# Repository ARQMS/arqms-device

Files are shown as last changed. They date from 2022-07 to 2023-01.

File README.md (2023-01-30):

View this project on [CADLAB.io](https://cadlab.io/project/26464). 

# Humi Device
The humi device is a portable air qualitity measure device which is connected to a MQTT Broker. This enables
a flexible way the measure the air qualitity without any cable management. The device is powered by a 2000mAh battery
and can be recharged with any 5V USB-C charger.<br />
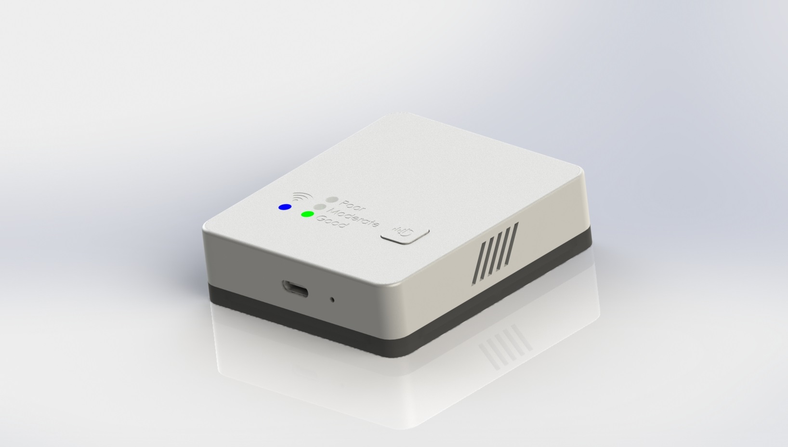
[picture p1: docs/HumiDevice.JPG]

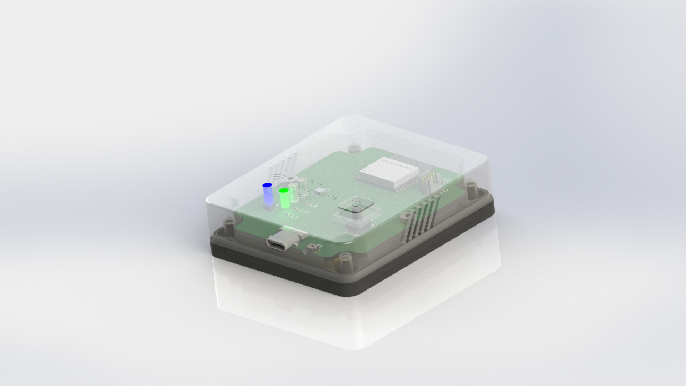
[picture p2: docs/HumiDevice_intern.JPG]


# Contribute
The project is documented in Github Wiki Page

## IDE and SDK
The ESP32-C3 is used as main CPU and WLAN module. Ensure you have installed the ESP-IDF Framework on your 
development machine according to [docs](https://docs.espressif.com/projects/esp-idf/en/latest/esp32c3/get-started/index.html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) or quick install instruction from [YoutTube](https://www.youtube.com/watch?v=byVPAfodTyY)

As standard IDE Visual Studio Code is used, open the `firmware` Folder.

# Knowing Issues
**Rev0** fixed in Rev1
- [x] PCB - Label "2000mAh @ 3.7V" is mirrored pn PCB back side
- [x] PCB - CN1 Label is mirrored on PCB back side
- [x] PCB - Wrong Buck Converter Footprint
- [x] BOM - Wrong Supplier Part Number for B5. Should be SSAL220100
- [x] Case - Bottom case has infinity small border for screw holder

**Rev1**
- [ ] PCB - USB Port is too small after JLCPCB fabrication
- [ ] PCB - If HW Switch is soldered, ESP does not start anymore. Workaround remove R23
- [ ] PCB - Green LED is very bright, increase resistor
- [ ] PCB - Wrong Q1 footprint

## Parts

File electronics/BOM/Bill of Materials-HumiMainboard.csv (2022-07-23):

Quantity | Designator | Description | Case/Package | Supplier 1 | JLCPCB | Manufacturer 1 | Manufacturer Part Number 1 | Name
1 | L1 | 2.2uH ±10% 2.45A 60mO SMD,3.0x3.0x1.5mm Power Inductors RoHS |  | Mouser | C43389 | TDK | VLS3015CX-2R2M-1 | SWPA3015S2R2MT
1 | D2 | SEMTECH - SRV05-4.TCT - ESD Protection Device, TVS, 17.5 V, SOT-23, 6 Pins, 5 V, 300 W | SOT-23 | Mouser | C13612 | Semtech | SRV05-4.TCT | SRV05-4.TCT
3 | SB1, SB2, SB3 | CHIP RESISTOR - SURFACE MOUNT 0OHMS ±1% 1/4W 0603 ROHS | 0603 |  |  |  |  | Solderbridge
1 | U4 | 2.5MHz 1.0A Synchronous Step Down Regulator in SOT23-5 | SOT-23-5 |  |  | Semtech | SC4626ZSKTRT | SC4626ZSKTRT
2 | R25, R26 | Chip Resistor, 100 KOhm, +/- 1%, 0.125 W, -55 to 155 degC, 0805 (2012 Metric), RoHS, Tape and Reel | 0805 | Digi-Key |  | Yageo | RC0805FR-07100KL | RC0805FR-07100KL
1 | Q1 | NST847BDP6T5G Series 45 V 100 mA Dual NPN General Purpose Transistor - SOT-963 |  | LCSC |  | ON Semiconductor | NST847BDP6T5G | NST847BDP6T5G
1 | LD3 | NeoPixel Addressable 1515 LEDs (1.5mm x 1.5mm) - 10 pack |  | Mouser |  | Adafruit Industries | 4492 | NeoPixel 1515
1 | T1 | P-Channel Enhancement Mode Field Effect Transistor 60V 0.12A 10Ohm 3-Pin SOT-23 Surface Mount T/R | SOT-23-3 |  |  | ON Semiconductor | NDS0610-G | NDS0610-G
1 | U3 | USB/AC Battery Charger with Power Path Management 20 QFN 4x4x0.9mm TUBE RoHS Compliant: Yes | QFN | Mouser |  | Microchip | MCP73871-1CCI/ML | MCP73871-1CCI/ML
2 | M1, M2 | M3 Mountinghole |  |  |  |  |  | M3 Mountinghole
1 | BAT1 | 3.7VWire Lead Term Rechargeable Lithium Battery Pack For Power Supply, 2000mAh |  | Eckstein |  | MIKROE | MIKROE-1120 | LiPo Akku
1 | D1 | 5V 5.6V Bidirectional 18.6V 9.4A (8/20us) SOD-523 ESD Protection Devices ROHS | SOD-523 | Mouser | C383211 | MCC | ESD5V0D5B-TP | LESD5D5.0CT1G
1 | LD4 | LED Uni-Color Red 630nm 2-Pin Chip LED T/R | 0603 | Digi-Key | C2286 | Wurth Electronics | 150060RS55040 | KT-0603R
1 | B2 | Switch Tactile N.O. SPST Button Gull Wing 0.05A 32VDC 1VA 200000Cycles 2N SMD Automotive T/R |  | Mouser | C221747 | ITT C&K | KMR221NGLFS | KMR221NGLFS
1 | CN1 | CML 1769 LMP T-1 3/4 INC Midget Screw .2A 2.5V Part of the VCC Family of Products |  | Mouser |  | Adafruit Industries | 1769 | JST-PH-2
2 | B1, B4 | SWITCH TACTILE SPST-NO 0.05A 12V |  | Mouser | C388883 | Panasonic | EVQP7C01P | EVQP7C01P
1 | U1 | 2.4 GHz WiFi, (802.11 b/g/n) and Bluetooth 5 module, Built around ESP32-C3, RISCV, singlecore, 4 MB flash, 15 GPIOs, Onboard |  | Digi-Key |  | Espressif Systems | ESP32-C3-WROOM-02-N4 | ESP32-C3-WROOM-02
1 | R9 |  |  | Mouser |  | Panasonic | ERJ3EKF1001V | ERJ-3EKF1001V
1 | R6 | 665kO ±1% 0.0625W ±100ppm/? 0402 Chip Resistor - Surface Mount RoHS | 0402 | Digi-Key |  | Vishay | CRCW0402665KFKED | CRCW0402665KFKED
2 | R10, R11 | Chip Resistor, 10 KOhm, +/- 1%, 100 mW, -55 to 155 degC, 0603 (1608 Metric), RoHS, Tape and Reel |  |  |  | Vishay | CRCW060310K0FKEA | CRCW060310K0FKEA
3 | C2, C8, C9 | SAMSUNG ELECTRO-MECHANICS - CL31A106KBHNNNE - SMD Multilayer Ceramic Capacitor, 10 µF, 50 V, 1206 [3216 Metric], ± 10%, X5R, CL Series | 1206 | Mouser | C13585 | Samsung | CL31A106KACLNNC | CL31A106KBHNNNE
2 | C4, C5 | Ceramic capacitor SMD-0603 22pF /50V NP0# J +-5%, Samsung, RoHS | 0603 | Mouser | C1653 | Samsung | CL10C220JB8NNNC | CL10C220JB8NNNC
3 | C10, C11, C12 | Ceramic capacitor SMD 0603 4.7 µF 16 V 10 % | 0603 | Mouser | C19666 | Samsung | CL10A475KO8NNNC | CL10A475KO8NNNC
1 | C13 | Ceramic capacitor SMD-0603 22uF /50V NP0# J +-5%, Samsung, RoHS | 0603 | Digi-Key | C1653 | Samsung | CL10A226KQ8NRNE | CL10A226KQ8NRNE
2 | C3, C14 | Cap Ceramic 1uF 50V X5R 10% SMD 0603 85C Cardboard T/R | 0603 | Mouser | C15849 | Samsung | CL10A105KB8NNNC | CL10A105KB8NNNC
6 | C1, C6, C7, C15, C16, C17 | Cap Ceramic 0.1uF 50V X7R 10% SMD 0603 125C Paper T/R | 0603 | Digi-Key | C14663 | Samsung | CL10B104KB8NNWC | CC0603KRX7R9BB104
1 | Q2 | 55V, Dual N-Ch, 35 m? max, Automotive MOSFET, SO8, OptiMOS™, PG-DSO-8-7, RoHS | SOIC | Mouser |  | Infineon | BSO604NS2XUMA1 | BSO604NS2XUMA1
1 | U2 | Pressure, Temperature and Humidity Sensor Digital Output 1.8V 8-Pin LGA | LGA | Digi-Key |  | Bosch Tools | BME680 | BME680
1 | B3 | Switch Tactile N.O. SPST Square Button Gull Wing 0.05A 12VDC 0.98N SMD Bulk | SMD/SMT | Mouser |  | APEM | ADTSM644KV | ADTSM644KV
1 | CN2 | USB Type - Connector, Mid-mount, SMT, CH-0.52, 16pos |  | Mouser |  | Molex | 216990-0001 | 216990-0001
1 | R13 | 5.6kO ±1% 0.1W ±100ppm/? 0603 Chip Resistor - Surface Mount RoHS | 0603 | LCSC | C23189 | Panasonic | ERJU03F5601V | 0603WAF5601T5E
2 | R17, R18 | 5.1kO ±1% 0.1W ±100ppm/? 0603 Chip Resistor - Surface Mount RoHS | 0603 | Mouser | C23186 | Panasonic | ERJU03F5101V | 0603WAF5101T5E
4 | R15, R19, R20, R21 | 470O ±1% 0.1W ±100ppm/? 0603 Chip Resistor - Surface Mount RoHS | 0603 | Mouser | C23179 | Panasonic | ERJU03F4700V | 0603WAF4700T5E
1 | R8 | 330kO ±1% 0.1W ±100ppm/? 0603 Chip Resistor - Surface Mount RoHS | 0603 | LCSC |  | Uniroyal | 0603WAF3303T5E | 0603WAF3303T5E
1 | R14 | 22kO ±1% 0.1W ±200ppm/? 0603 Chip Resistor - Surface Mount RoHS | 0603 | Mouser | C31850 | Panasonic | ERJU03F2202V | 0603WAF2202T5E
1 | R12 | 110kO ±1% 0.1W ±100ppm/? 0603 Chip Resistor - Surface Mount RoHS | 0603 | LCSC |  | Uniroyal | 0603WAF1103T5E | 0603WAF1103T5E
1 | R1 | 10kO ±1% 0.1W ±100ppm/? 0603 Chip Resistor - Surface Mount RoHS | 0603 | Mouser | C25804 | Panasonic | ERJU03F1002V | 0603WAF1002T5E
2 | R7, R16 | 1kO ±1% 0.1W ±100ppm/? 0603 Chip Resistor - Surface Mount RoHS | 0603 | LCSC | C21190 | Uniroyal | 0603WAF1001T5E | 0603WAF1001T5E
5 | R2, R3, R22, R23, R24 | 0O ±1% 0.1W ±200ppm/? 0603 Chip Resistor - Surface Mount RoHS | 0603 |  | C21189 | Royal Electronic Factory | 0603WAF0000T5E | 0603WAF0000T5E
2 | R4, R5 | 100kO ±1% 0.0625W ±100ppm/? 0402 Chip Resistor - Surface Mount RoHS | 0402 | Mouser | C25741 | Panasonic | ERJ-2RKF1003X | 0402WGF1003TCE
3 | LD1, LD2, LD6 | LED Uni-Color Green 518nm 2-Pin Chip LED T/R | 0603 | Farnell | C72043 | Wurth Electronics | 150060GS84000 | 19-217/GHC-YR1S2/3T
1 | LD5 | SMD LED yellow 1.7. . .2.3 V 0603, 19-213/Y2C-CQ2R2L/3T, Everlight Electronics | 0603 | Digi-Key | C72038 | Wurth Electronics | 150060YS55040 | 19-213/Y2C-CQ2R2L/3T

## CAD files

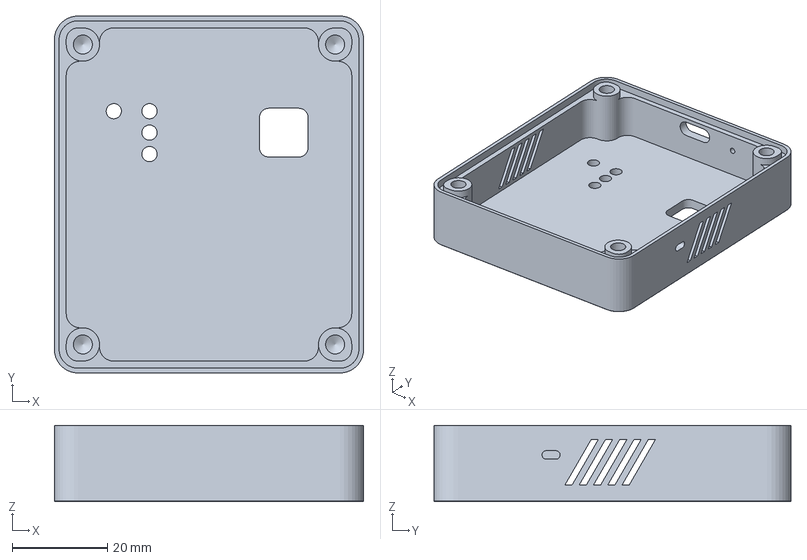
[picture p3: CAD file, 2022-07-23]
housing/CaseTop.3MF
65.0 x 75.0 x 16.0 mm

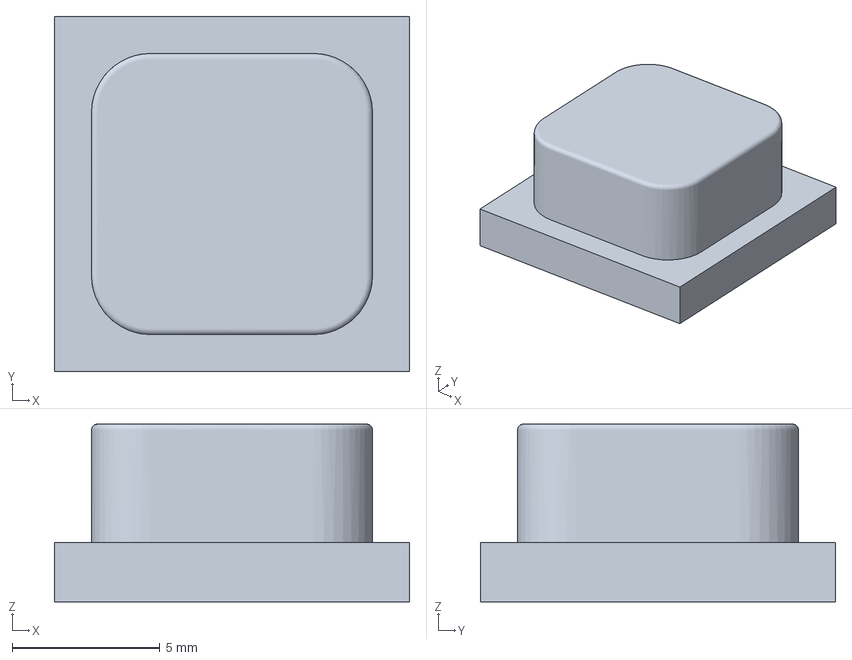
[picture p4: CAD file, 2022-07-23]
housing/Button.3MF
12.0 x 12.0 x 6.01 mm

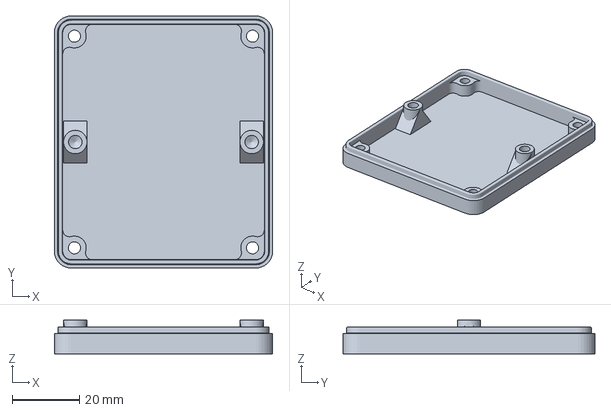
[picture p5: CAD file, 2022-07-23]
housing/CaseBottoml.3MF
65.0 x 75.0 x 10.0 mm

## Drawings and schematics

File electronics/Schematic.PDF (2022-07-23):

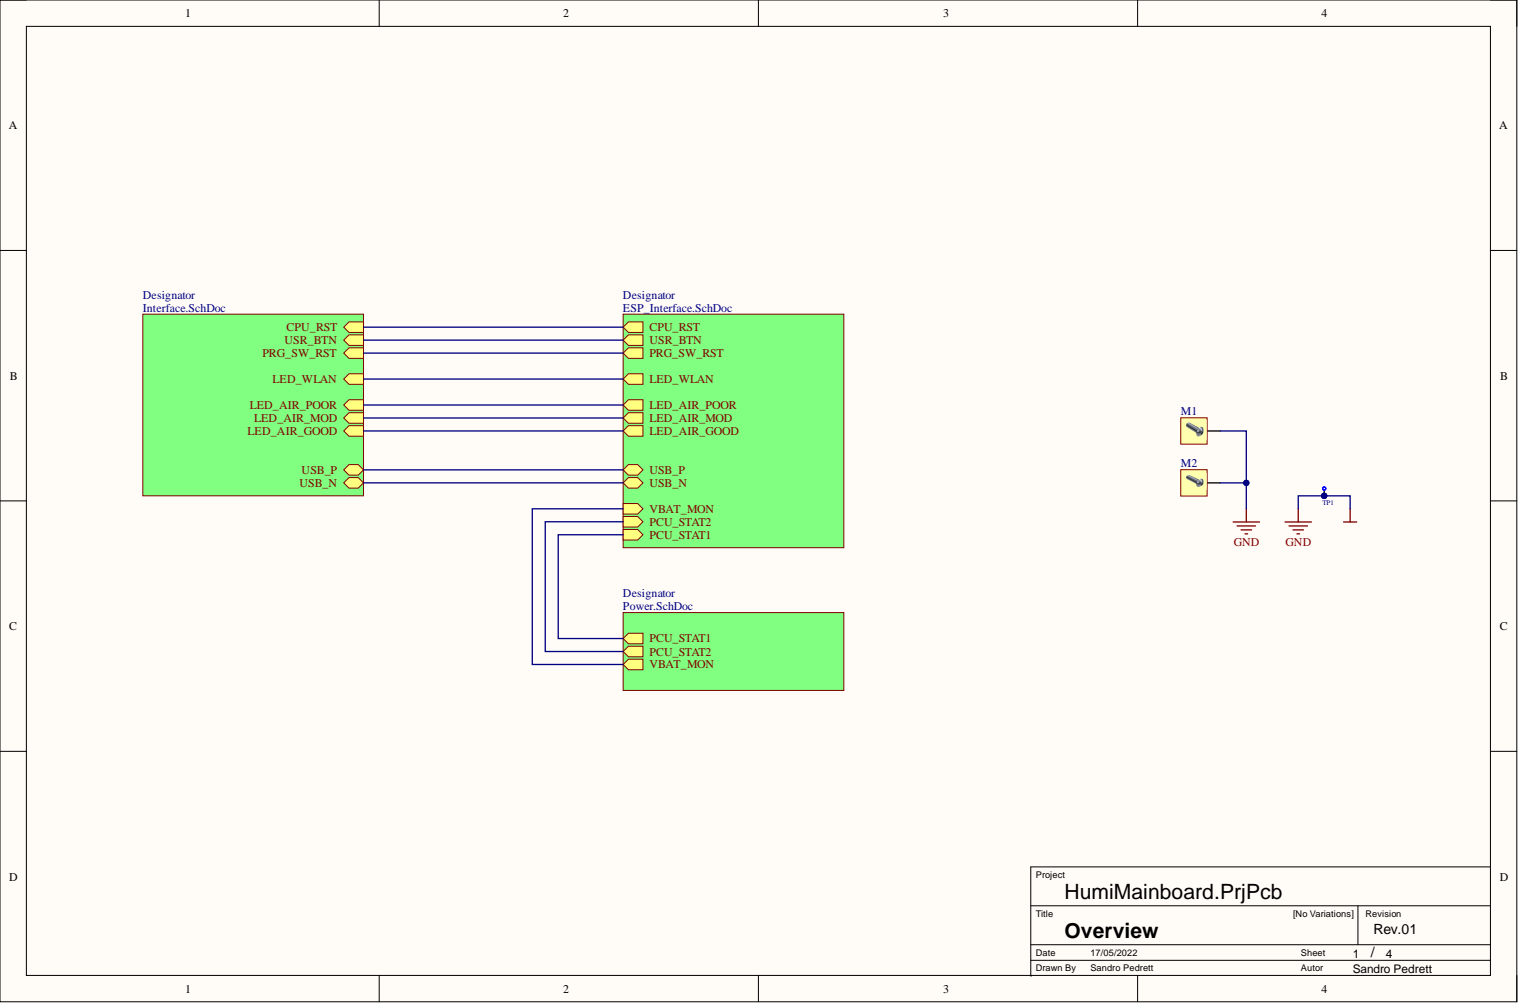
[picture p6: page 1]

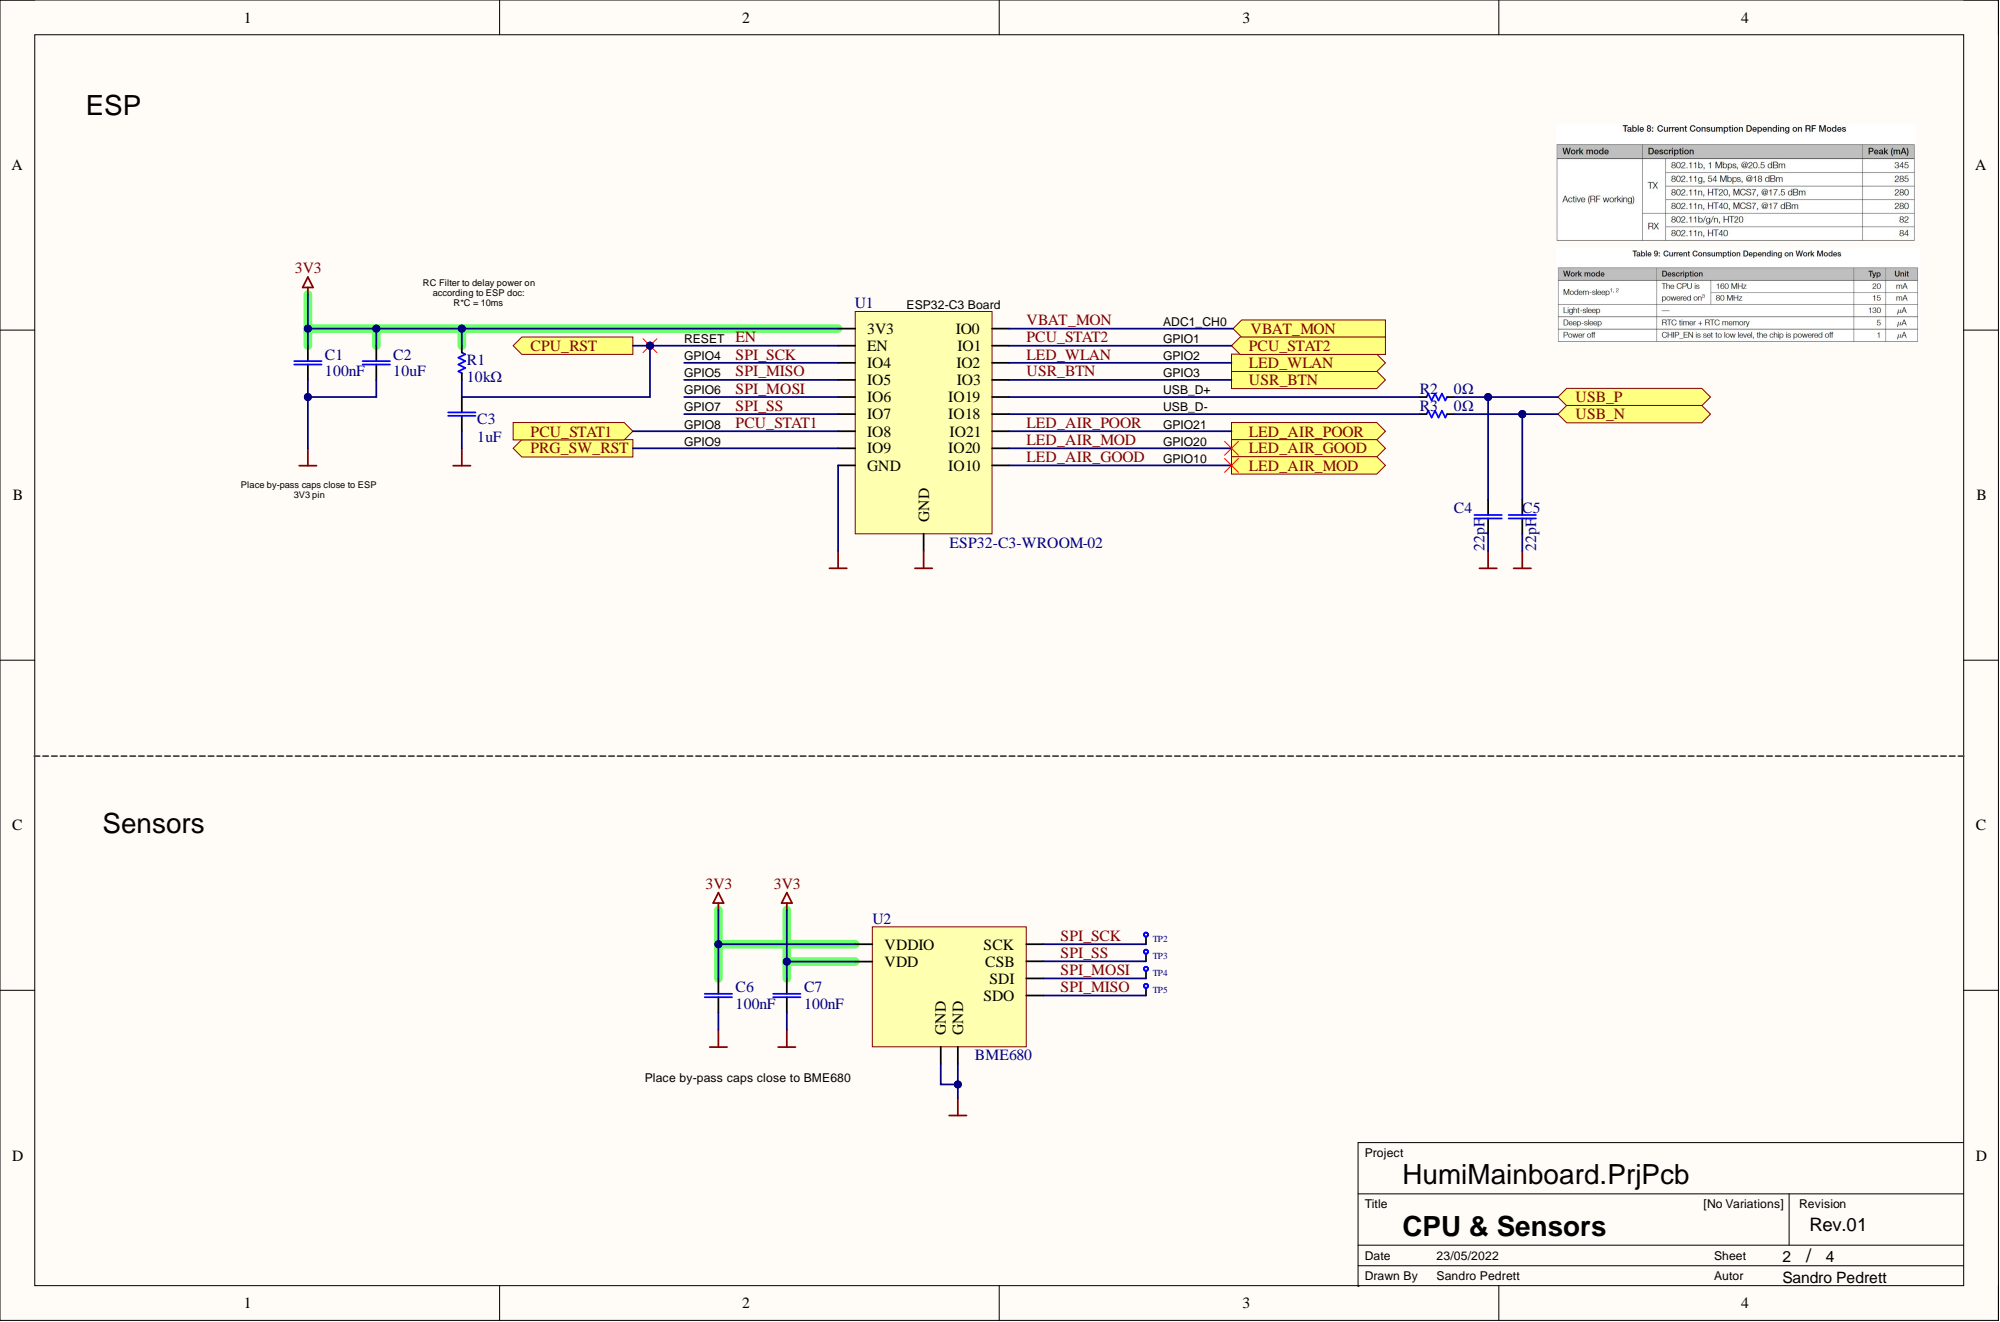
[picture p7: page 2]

RC Filter to delay power on
according to ESP doc:

GPIO4 SPI_SCK R1 SPI_MISO 10kΩ GPIO5 GPIO6 SPI_MOSI

Place by-pass caps close to ESP

Place by-pass caps close to BME680

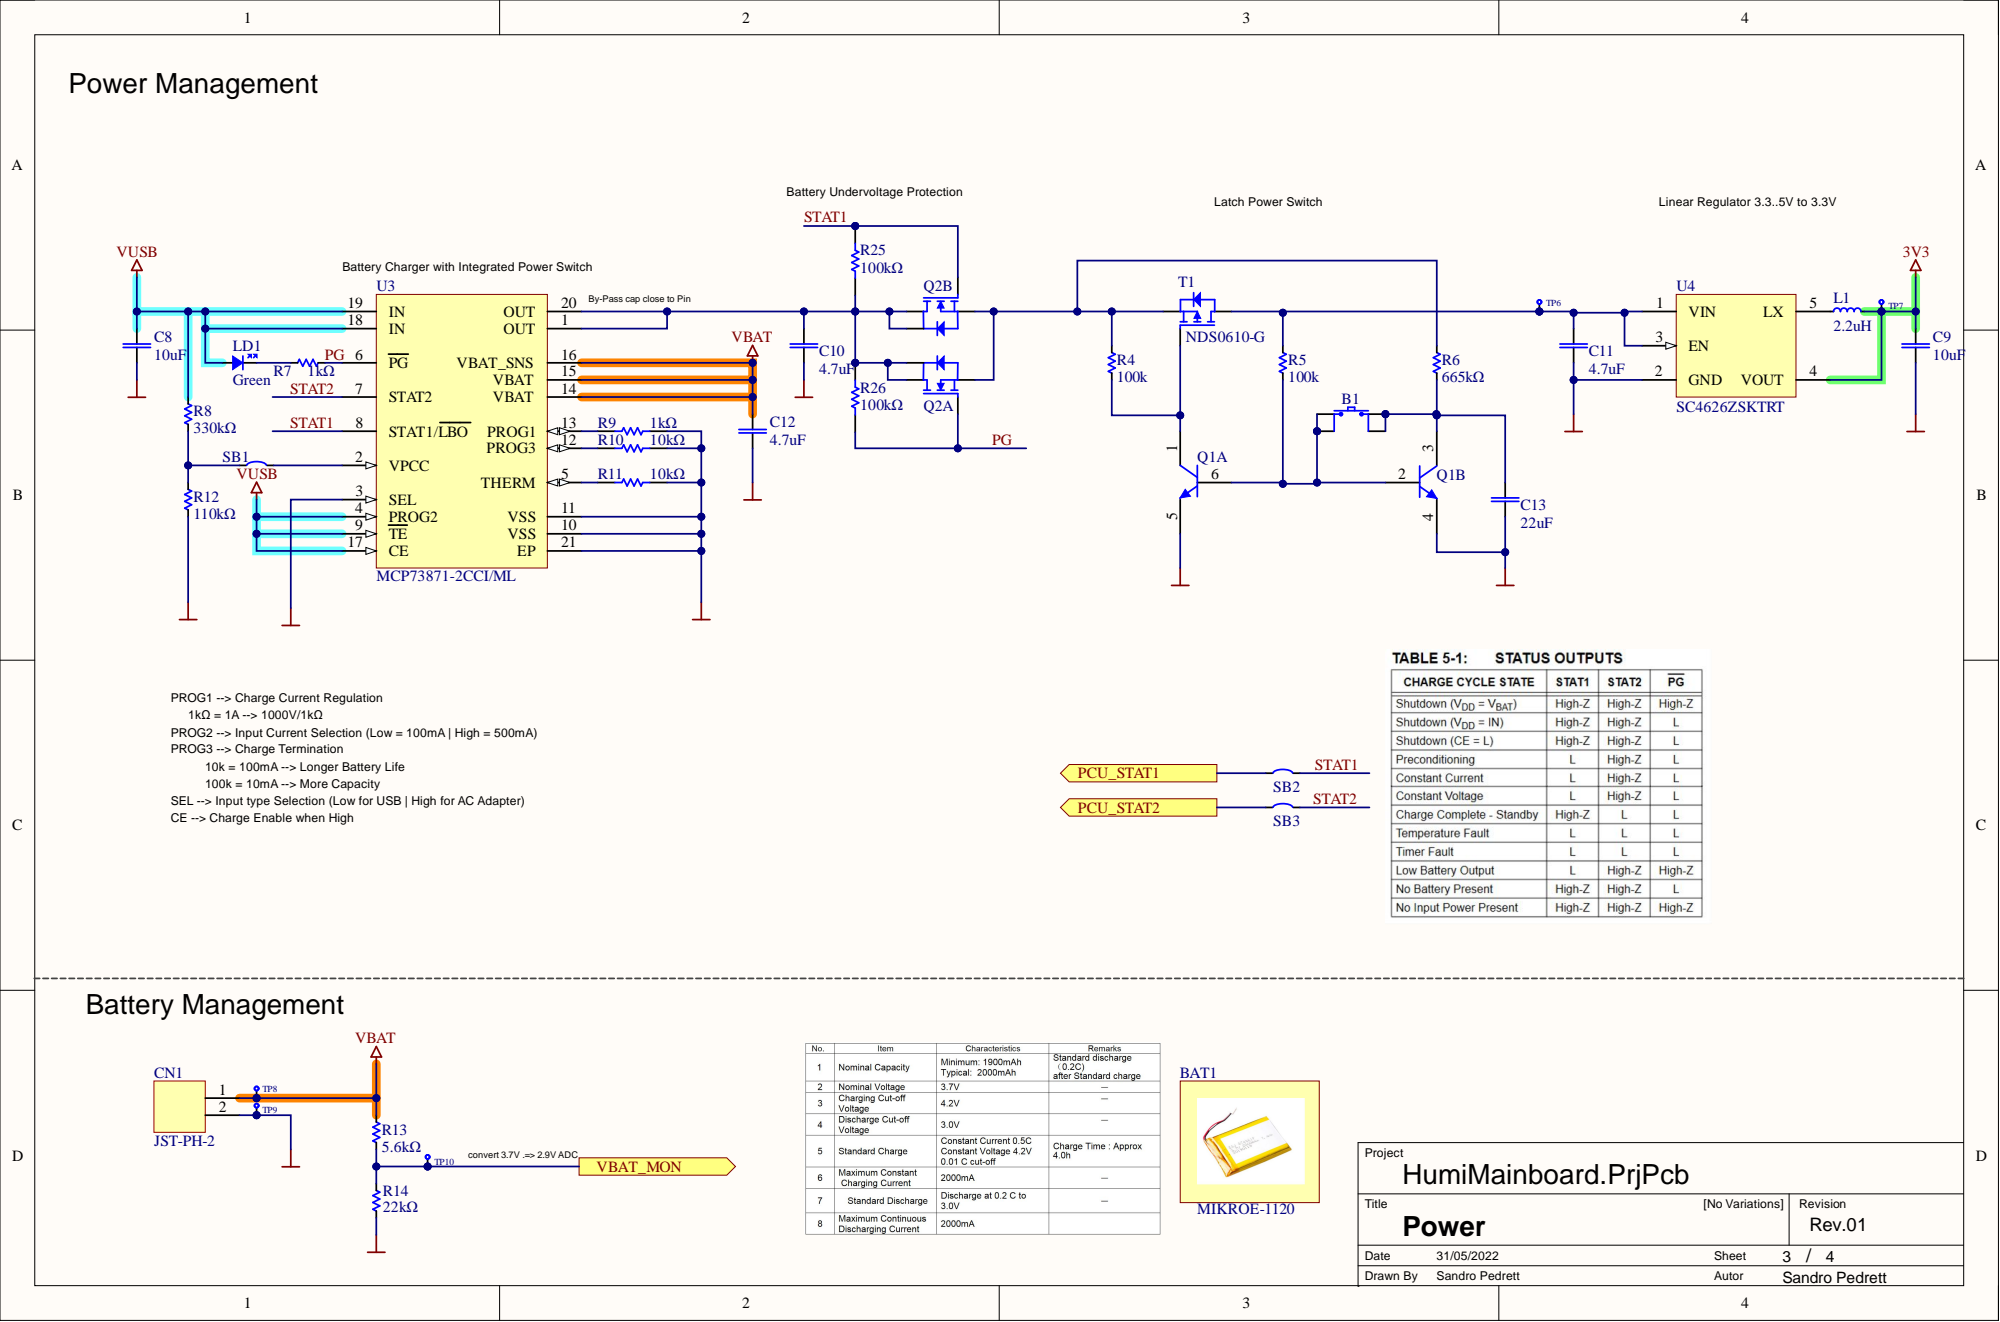
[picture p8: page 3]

Battery Charger with Integrated Power Switch

By-Pass cap close to Pin

PROG1 --> Charge Current Regulation
PROG2 --> Input Current Selection (Low = 100mA | High = 500mA)
PROG3 --> Charge Termination

SEL --> Input type Selection (Low for USB | High for AC Adapter)
CE --> Charge Enable when High

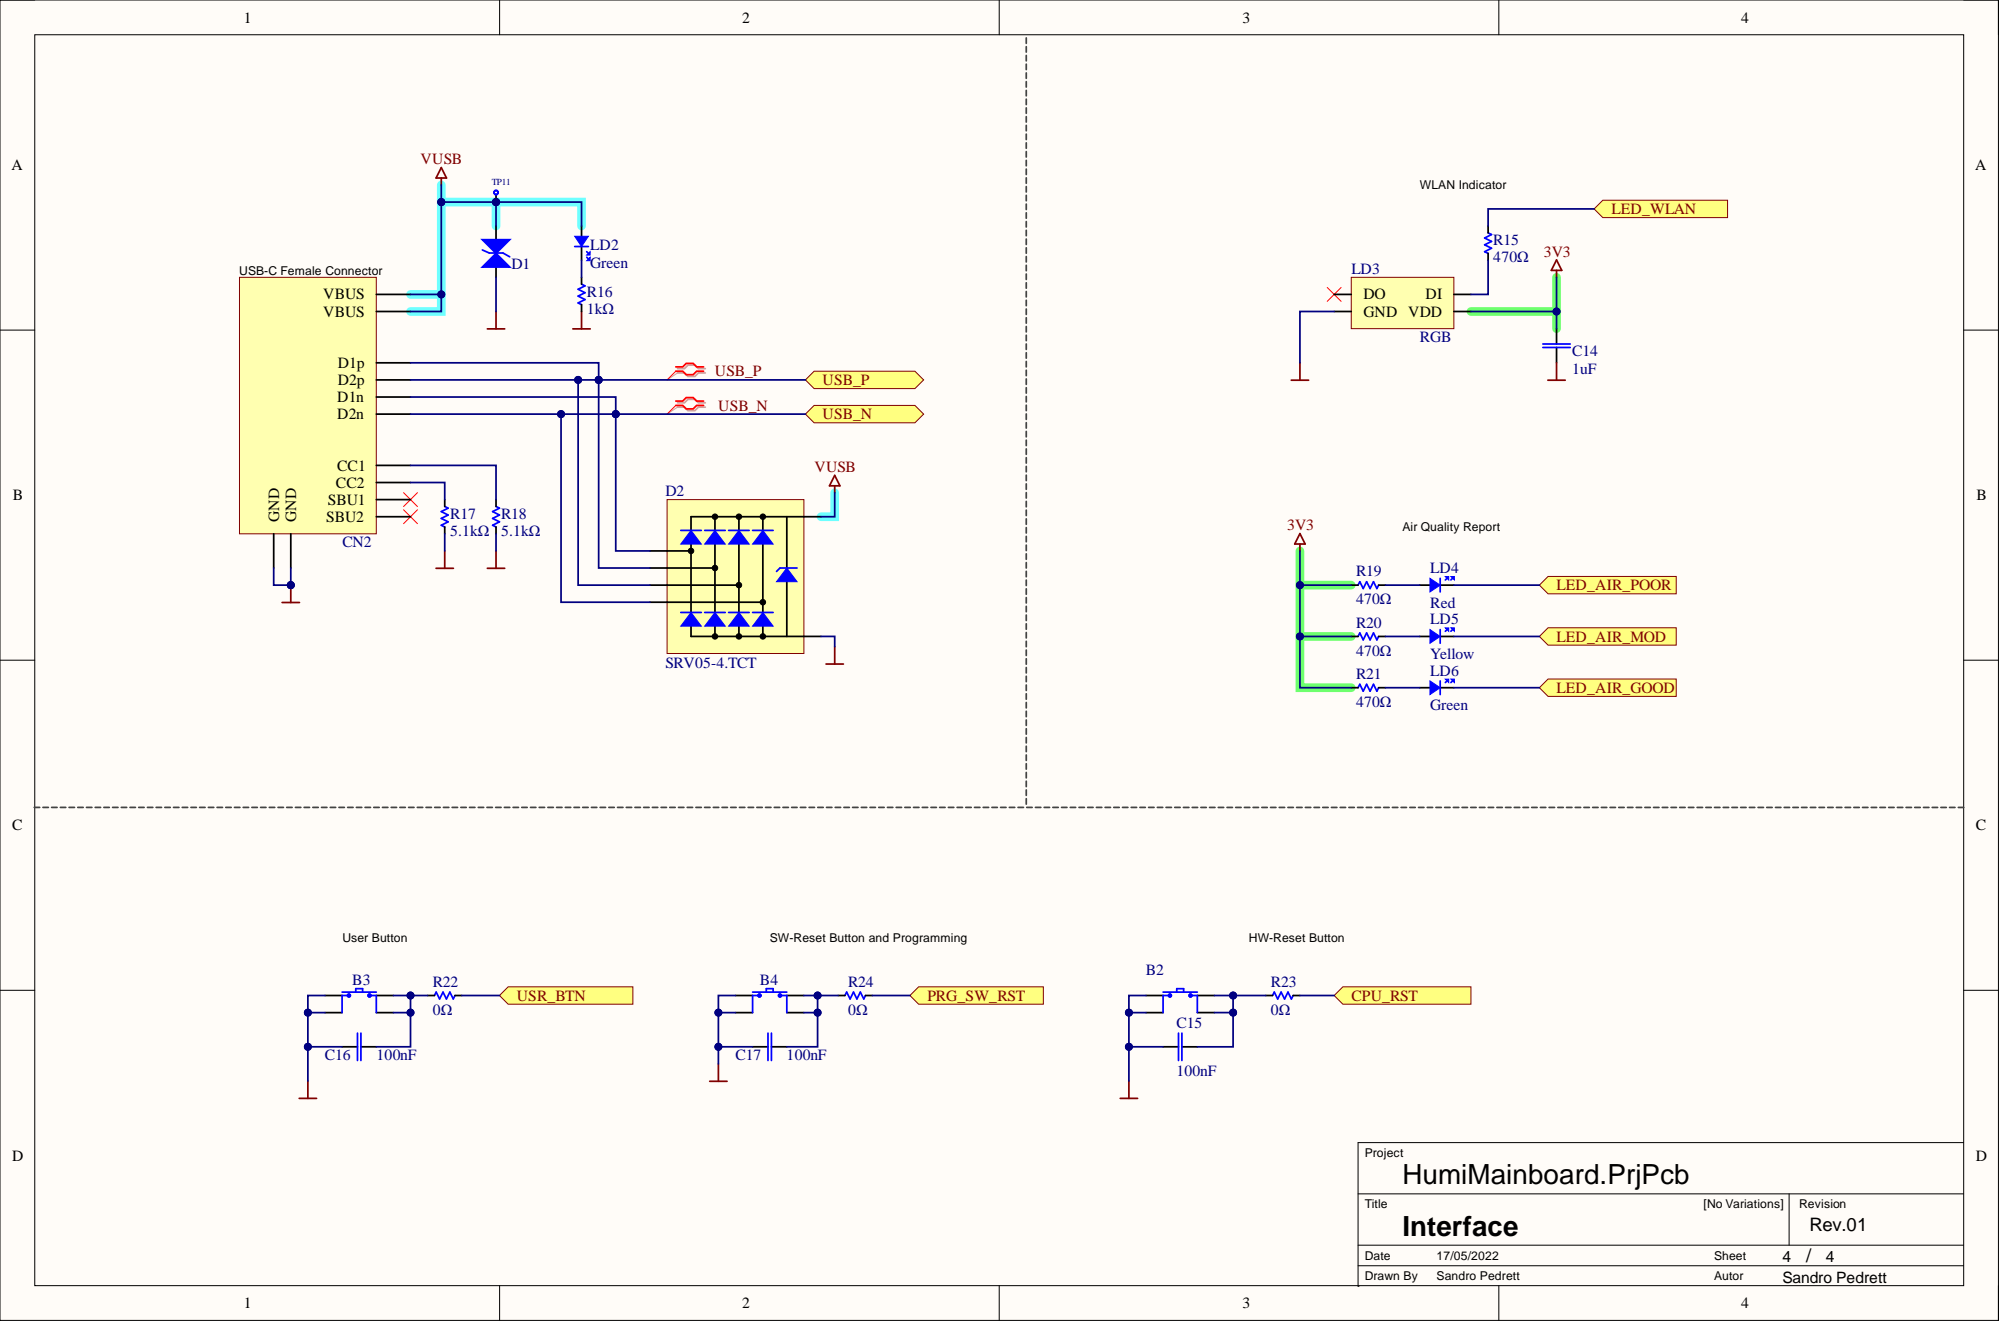
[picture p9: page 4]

USB_N

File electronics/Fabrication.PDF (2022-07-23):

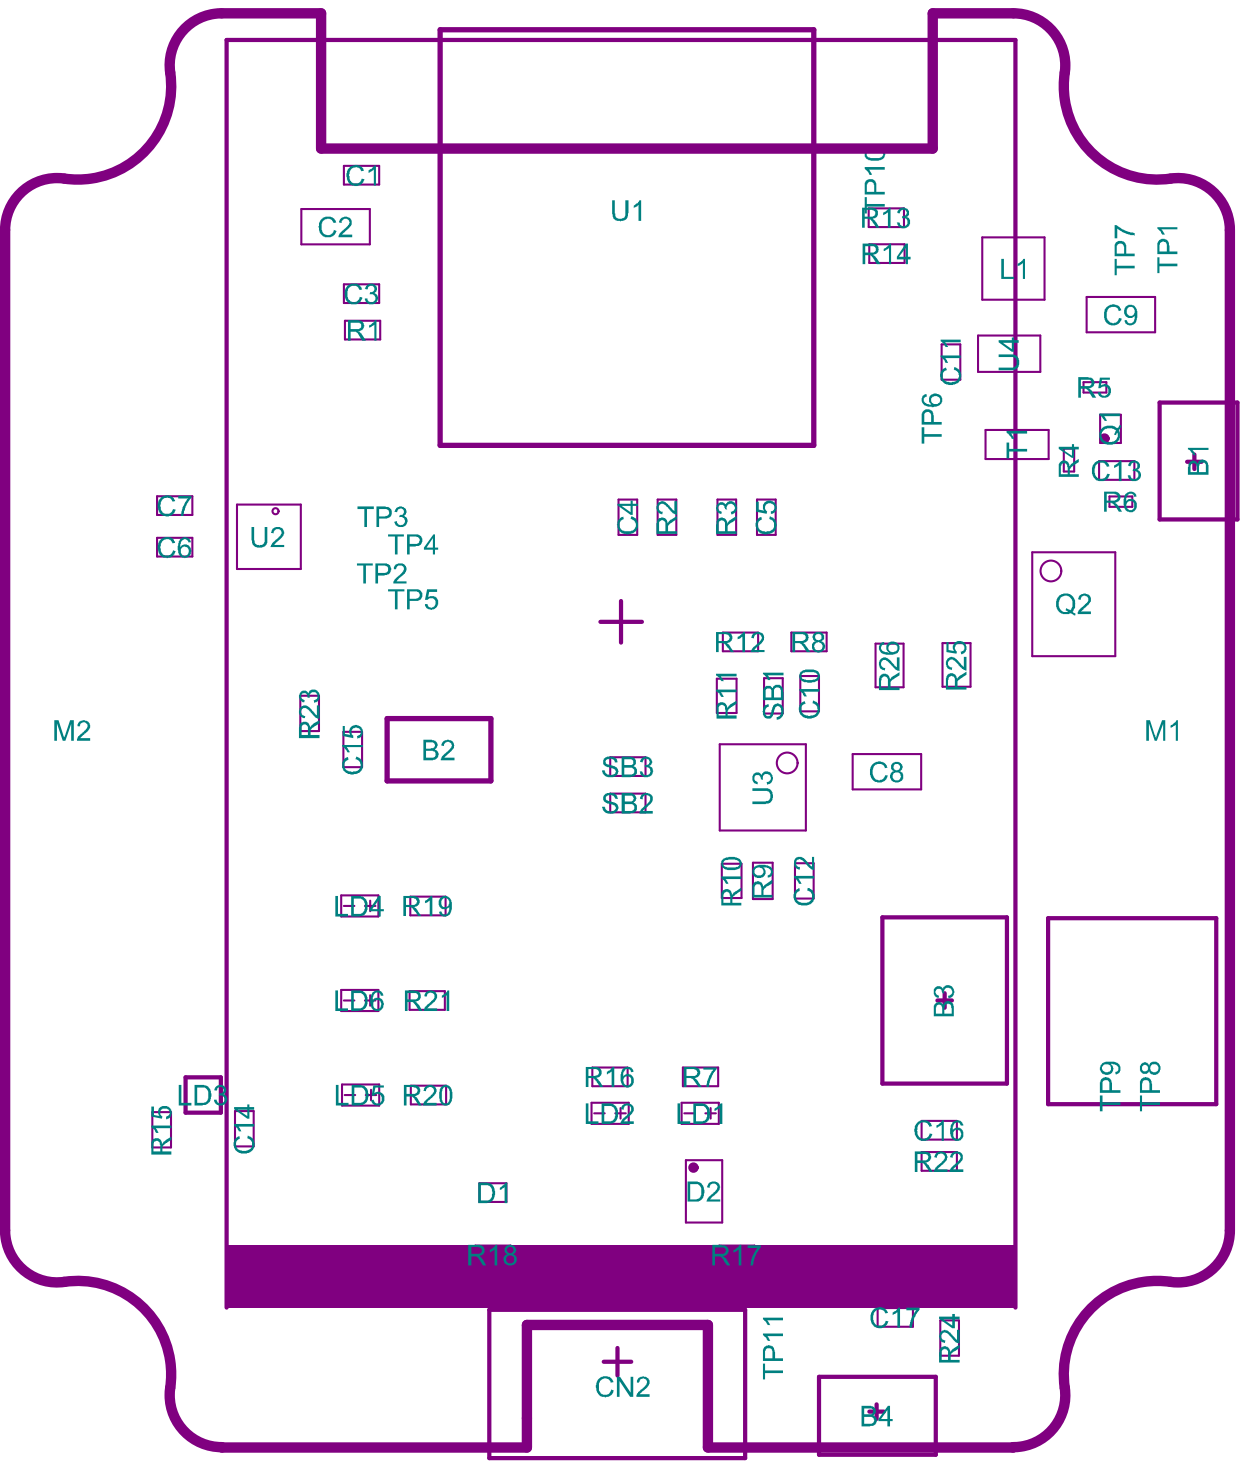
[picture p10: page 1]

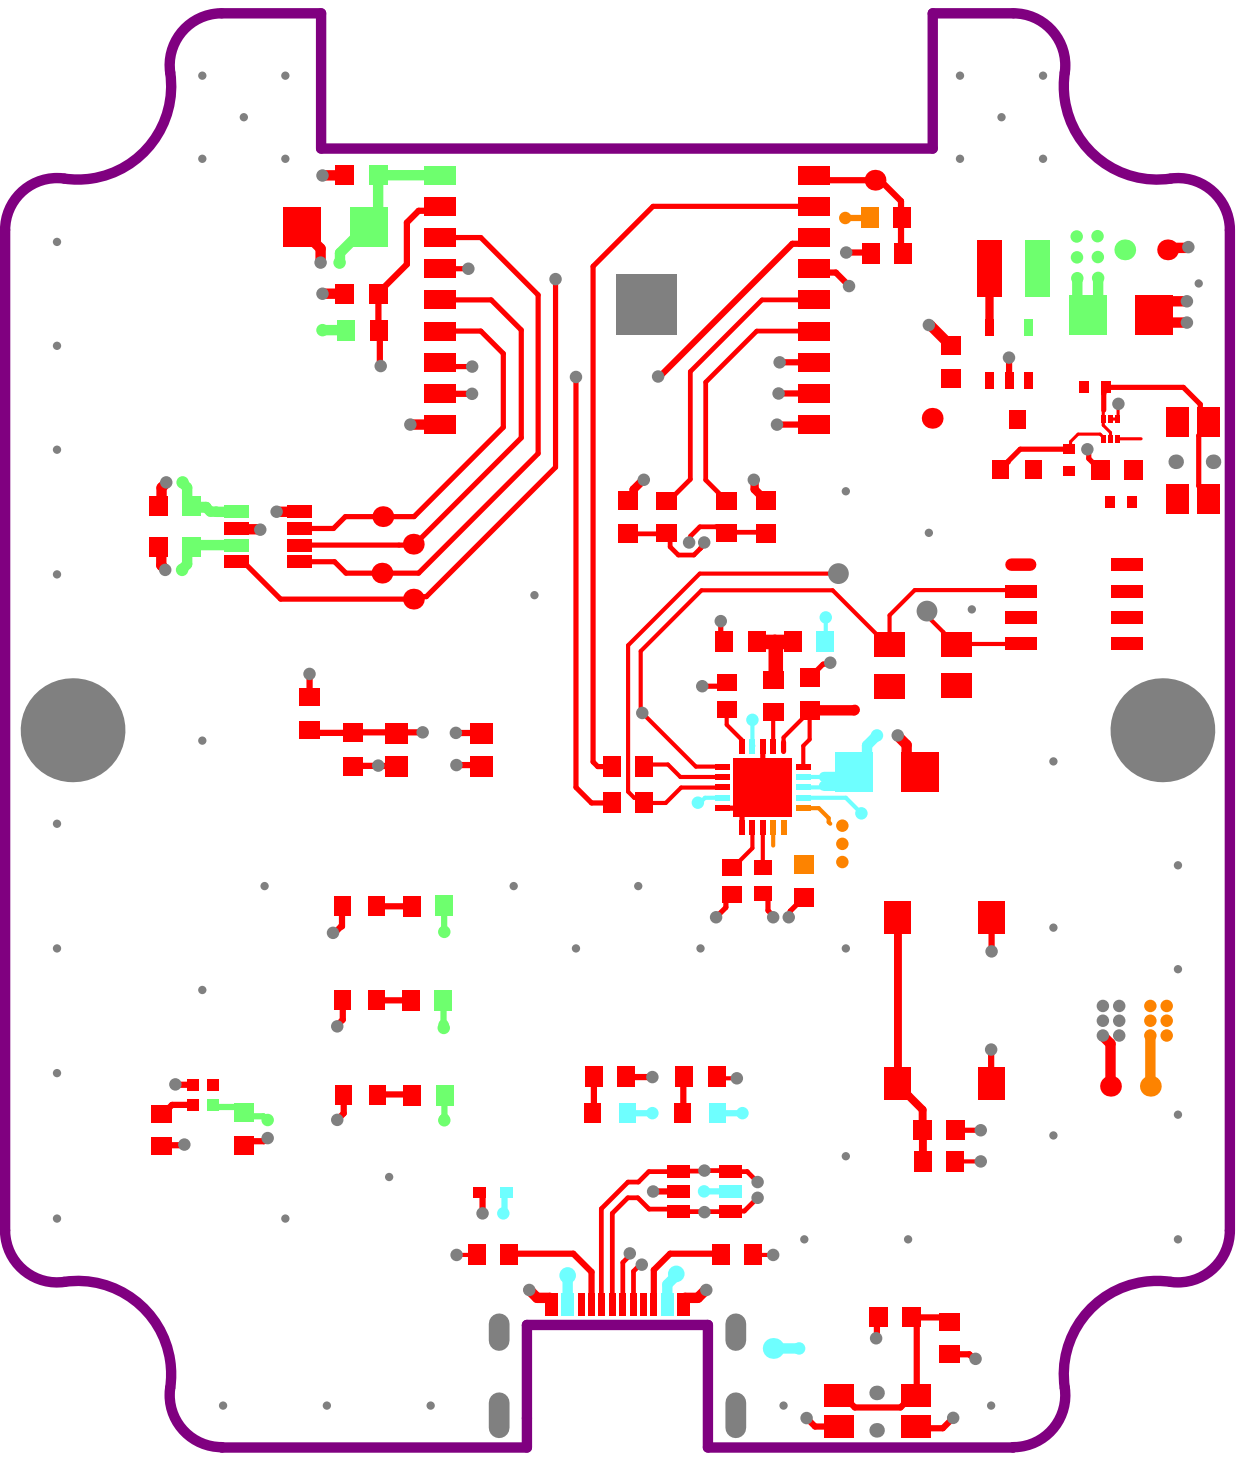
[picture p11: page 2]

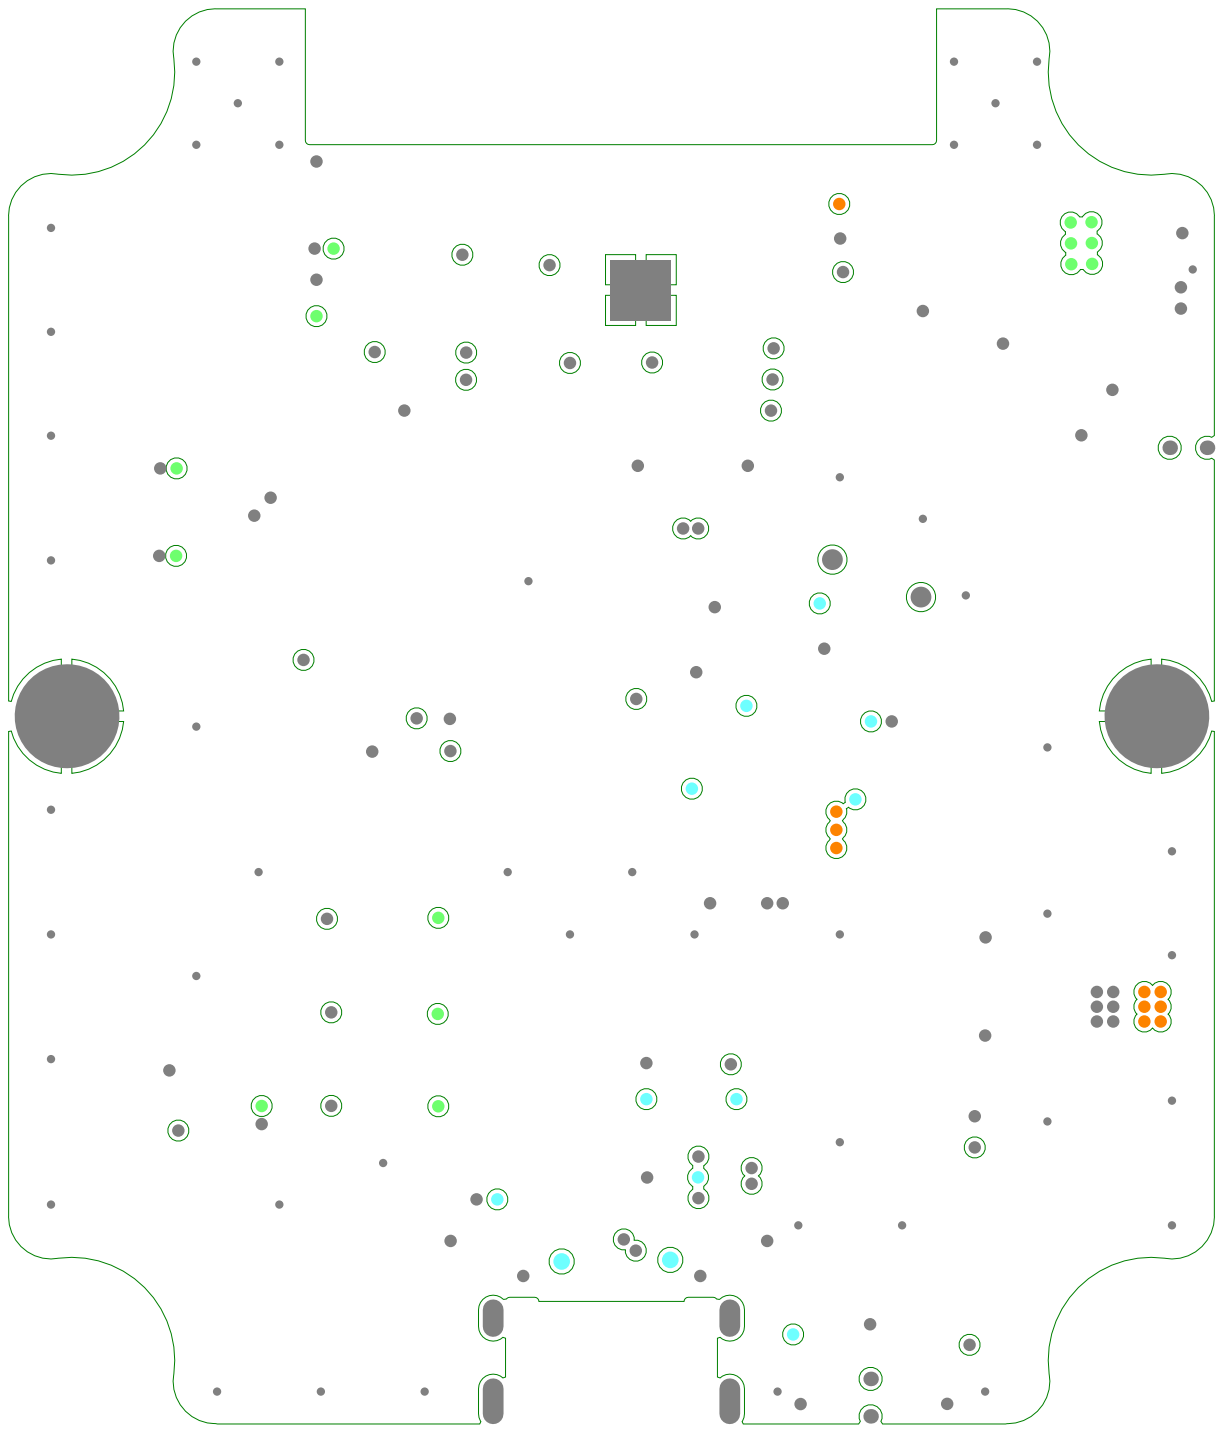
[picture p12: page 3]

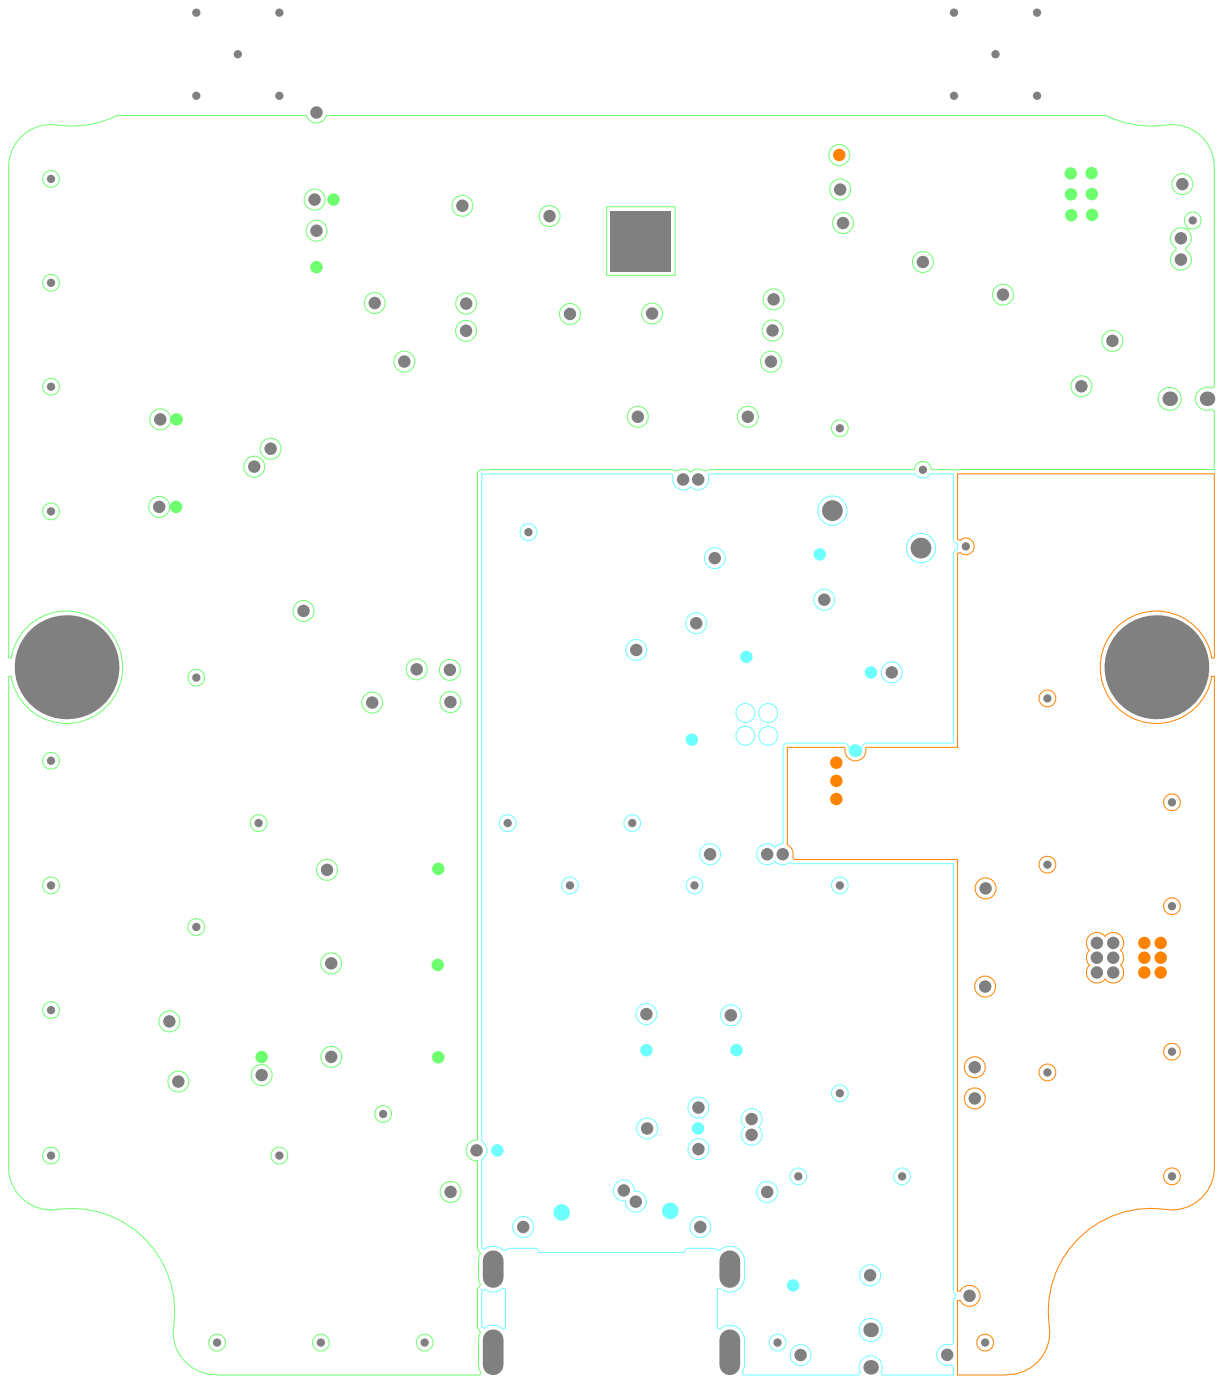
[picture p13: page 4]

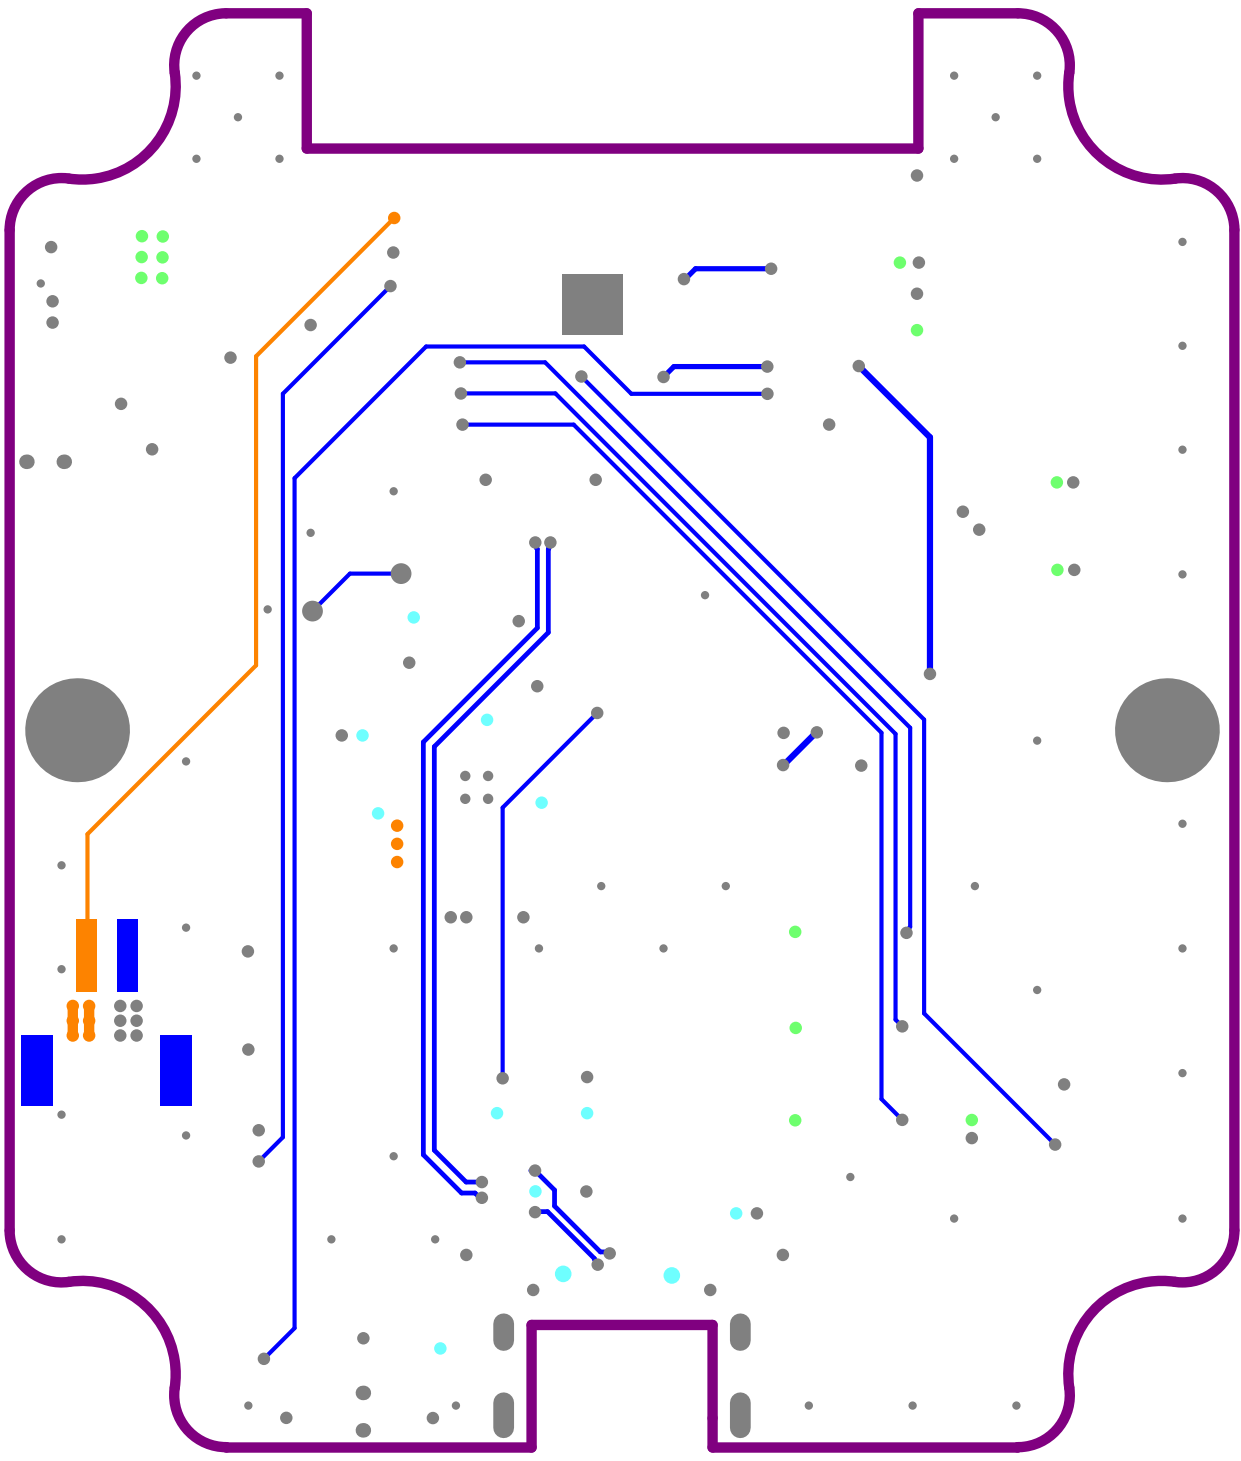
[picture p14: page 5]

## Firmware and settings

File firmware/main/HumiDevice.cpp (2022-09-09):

// FreeRTOS includes
#include <freertos/FreeRTOS.h>
#include <freertos/task.h>

// Platform
#include <HumiDevice.Platform/Platform.h>
#include <HumiDevice.Rtos/EventRuntime.h>

// Project includes
#include "Drivers/ApplicationHardwareConfig.h"
#include "Drivers/StartupController.h"
#include "Control/ControlTask.h"
#include "Control/PushBtn/PushBtnCtrlTask.h"
#include "Control/PushBtn/GpioIrqHandler.h"
#include "GuiUpdater/GuiUpdaterTask.h"
#include "CloudLink/CloudLinkTask.h"
#include "MeasSensor/MeasSensorTask.h"
#include "MeasFilter/MeasFilterTask.h"
#include "PowerManagement/PowerManagementTask.h"

// Create task definitions
CREATE_TASK_DEF(Control, 0xC00, 10) // 3kB Stack
CREATE_TASK_DEF(GuiUpdater, 0xC00, 10) // 3kB Stack
CREATE_TASK_DEF(MeasSensor, 0xC00, 10) // 3kB Stack
CREATE_TASK_DEF(MeasFilter, 0xC00, 10) // 3kB Stack
CREATE_TASK_DEF(CloudLink, 0x8000, 11) // 4kB Stack
CREATE_TASK_DEF(PushBtnCtrl, 0xC00, 9) // 3kB Stack
CREATE_TASK_DEF(PowerManagement, 0x800, 11) // 2kB Stack

/**
 * The entry point for humi device. This is called after second bootloader has 
 * initialized all peripherals pins and c++/c domain.
 * 
 * It is configured as a FreeRTOS task.
 * @see https://docs.espressif.com/projects/esp-idf/en/latest/esp32c3/api-reference/system/freertos.html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
 */
extern "C" void app_main(void) {
    ESP_LOGI("HumiDevice", "Application initialization...");

    // initialize hardware
    StartupController::initialize();
    StartupController::initializeGpio();
    StartupController::initializeSpi1();
    StartupController::initializeAdc1();
    StartupController::initializeIrq();

    // create tasks
    ControlTask& control = *createControlTask();
    GuiUpdaterTask& guiUpdater = *createGuiUpdaterTask();
    CloudLinkTask& cloudLink = *createCloudLinkTask();
    MeasSensorTask& measSensor = *createMeasSensorTask();
    MeasFilterTask& measFilter = *createMeasFilterTask();
    PowerManagementTask& powerManagement = *createPowerManagementTask();
    PushBtnCtrlTask& btnCtrl = *createPushBtnCtrlTask();
    GpioIrqHandler& gpioHandler = GpioIrqHandler::getInstance();

    // connect tasks
    control.Gui.connect(guiUpdater);
    control.CloudLink.connect(cloudLink);
    control.MeasSensor.connect(measSensor);
    control.MeasFilter.connect(measFilter);
    guiUpdater.Control.connect(control);
    cloudLink.Status.connect(control);
    cloudLink.Status.connect(guiUpdater);
    cloudLink.Control.connect(control);
    measSensor.Measurement.connect(measFilter);
    measSensor.Status.connect(guiUpdater);
    measFilter.Measurement.connect(cloudLink);
    measFilter.Measurement.connect(guiUpdater);
    measFilter.Measurement.connect(control);
    gpioHandler.PushBtn.connect(btnCtrl);
    btnCtrl.Control.connect(control);
    btnCtrl.Control.connect(guiUpdater);
    powerManagement.Control.connect(control);

    // start tasks
    startGuiUpdaterTask();
    startControlTask();
    startCloudLinkTask();
    startMeasSensorTask();
    startMeasFilterTask();
    startPushBtnCtrlTask();
    startPowerManagementTask();
}

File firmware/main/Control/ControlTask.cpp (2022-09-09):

#include "ControlTask.h"

#include "esp_sleep.h"

#include "Events/EventIdentifiers.h"
#include "Events/WifiSettingsEvent.h"
#include "Events/DeviceInfoEvent.h"
#include "Events/DeviceStatusEvent.h"
    
StorageDriverIfc* ControlTask::s_pNvsStorageDriver = NULL;

ControlTask::ControlTask() :
    Gui(),
    CloudLink(),
    m_coreSm(),
    m_lastWifiStatus(),
    m_lastBatteryStatus(),
    m_wifiReceived(false),
    m_batteryReceived(false),
    m_deviceStatusSent(false),
    m_sensorStatusSent(false),
    m_displayOn(false) {
}

ControlTask::~ControlTask() {
}

void ControlTask::onInitialize()  {
    assert(s_pNvsStorageDriver != NULL);
}

void ControlTask::onStart() {
    WifiSettingsEvent wifiSettings;
    s_pNvsStorageDriver->readWifiConfig(&wifiSettings);

    DeviceInfoEvent deviceSettings;
    s_pNvsStorageDriver->readDeviceConfig(&deviceSettings);

    if (wifiSettings.getMode() == WifiMode::AP) {
        m_coreSm.onServiceMode();
    }

    CloudLink.send(EventIdentifiers::DEVICE_INFO_EVENT, &deviceSettings);
    CloudLink.send(EventIdentifiers::WIFI_SETTINGS_EVENT, &wifiSettings);

    // device started with GPIO, ISR already handle so we must send event manualy
    if (esp_sleep_get_wakeup_cause() == ESP_SLEEP_WAKEUP_GPIO) {
        ButtonEvent event(ButtonId::USER, ButtonStatus::SHORT_PRESS);
        Gui.send(EventIdentifiers::DEVICE_BTN_EVENT, &event);
    }
}

void ControlTask::onHandleEvent(EventId eventId, Deserializer* pEvent) {
    switch (eventId) {
        case EventIdentifiers::WIFI_STATUS_EVENT: 
            onHandleWifiStatus(WifiStatusEvent(*pEvent));
            break;
        
        case EventIdentifiers::BATTERY_LEVEL_EVENT:
            onHandleBatteryStatus(BatteryStatusEvent(*pEvent));
            break;

        case EventIdentifiers::DEVICE_BTN_EVENT: 
            onHandleButton(ButtonEvent(*pEvent));
            break;

        case EventIdentifiers::DEVICE_CONFIG_EVENT:
            onHandleDeviceConfig(DeviceConfigEvent(*pEvent));
            break;

        case EventIdentifiers::DISPLAY_INFO_EVENT:
            onHandleDisplayInfo(DisplayInfoEvent(*pEvent));
            break;

    default:
        break;
    }
}

void ControlTask::onHandleTimer(const TimerId timerId) {
    // nothing to do
}

void ControlTask::onHandleWifiStatus(const WifiStatusEvent& status) {
    m_lastWifiStatus = status;
    m_wifiReceived = true;
    sendDeviceStatus();

    if (m_coreSm.isCurrentState(CoreSM::State::Service)) {
        if (status.getStatus() == WifiStatus::TIMEOUT
         || status.getStatus() == WifiStatus::CLIENT_DISCONNECTED) {
            shutdown();
            return;
        }
    }
    else if (m_coreSm.isCurrentState(CoreSM::State::BootUp)) {
        if (status.getStatus() == WifiStatus::TIMEOUT
         || status.getStatus() == WifiStatus::DISCONNECTED) {
            m_coreSm.onServiceMode();

            WifiSettingsEvent event;
            event.setMode(WifiMode::AP);
            CloudLink.send(EventIdentifiers::WIFI_SETTINGS_EVENT, &event);
        }
        else if (status.getStatus() == WifiStatus::MQTT_CONNECTED) {
            m_coreSm.onRunning();

            MeasSensor.send(EventIdentifiers::SENSOR_SNAPSHOT);
        }
    }
    else if (m_coreSm.isCurrentState(CoreSM::State::Running)) {
        if (status.getStatus() == WifiStatus::TIMEOUT
         || status.getStatus() == WifiStatus::DISCONNECTED) {
            m_coreSm.onServiceMode();

            WifiSettingsEvent event;
            event.setMode(WifiMode::AP);
            CloudLink.send(EventIdentifiers::WIFI_SETTINGS_EVENT, &event);
        }

        m_deviceStatusSent |= status.getLastSentMsg() == EventIdentifiers::DEVICE_STATUS_EVENT;
        m_sensorStatusSent |= status.getLastSentMsg() == EventIdentifiers::SENSOR_DATA_EVENT;
        sleepConditional();
    }
}

void ControlTask::onHandleBatteryStatus(const BatteryStatusEvent& status) {
    m_lastBatteryStatus = status;
    m_batteryReceived = true;
    sendDeviceStatus();
}

void ControlTask::onHandleButton(const ButtonEvent& button) {
    if (button.getButtonId() == ButtonId::SW_RESET) {
        if (button.getStatus() == ButtonStatus::LONG_PRESS) {
            s_pNvsStorageDriver->reset();
        }
        
        restart();
    }
}

void ControlTask::onHandleDisplayInfo(const DisplayInfoEvent& info) {
    m_displayOn = info.getStatus();

    sleepConditional();
}

void ControlTask::onHandleDeviceConfig(const DeviceConfigEvent& config) {
    char8_t channel[DeviceConfigEvent::MAX_CHANNEL_LENGTH];
    config.getChannel(channel);
    uint32_t interval = config.getInterval();

    if (strlen(channel) > 0) {
        s_pNvsStorageDriver->put(ESP_CTRL_PROP_DEVICE_CHANNEL, channel, sizeof(channel));
    }
    if (interval > 0) {
        s_pNvsStorageDriver->put(ESP_CTRL_PROP_DEVICE_INTERVAL, &interval, sizeof(interval));
    }
    s_pNvsStorageDriver->commit();

    // NOTE: configuration is only applied to application on bootUp process, so restart device manualy
}

void ControlTask::sendDeviceStatus() {
    // pre condition for sending device status
    if (!m_wifiReceived || !m_batteryReceived || !m_coreSm.isCurrentState(CoreSM::State::Running)) return;

    m_wifiReceived = false;
    m_batteryReceived = false;

    uint32_t uptime = pdTICKS_TO_MS(xTaskGetTickCount());
    DeviceStatusEvent deviceInfo(m_lastBatteryStatus, m_lastWifiStatus, uptime);

    CloudLink.send(EventIdentifiers::DEVICE_STATUS_EVENT, &deviceInfo);
}

void ControlTask::shutdown() {
    // TODO perform shutdown, seems IDF does not support shutdown, 
    // so we must connect GPIO 1 (PCU_STATE2) as output and connect to Latch Power or 
    // battery charger
    esp_restart();
}

void ControlTask::restart() {
    esp_restart();
}

void ControlTask::sleepConditional() {
    if (!m_deviceStatusSent || !m_sensorStatusSent || m_displayOn) return;
    
    m_deviceStatusSent = false;
    m_sensorStatusSent = false;
    m_displayOn = false;

    sleep();
}

void ControlTask::sleep() {
    // According to IDF Doc all communication peripherals
    // must be stopped before entering sleep mode 
    // https://docs.espressif.com/projects/esp-idf/en/latest/esp32c3/api-reference/system/sleep_modes.html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
    WifiSettingsEvent settings;
    settings.setMode(WifiMode::NONE);
    CloudLink.send(EventIdentifiers::WIFI_SETTINGS_EVENT, &settings);

    // wait at least 1 second to ensure phy are stopped
    vTaskDelay(pdMS_TO_TICKS(1000));

    DeviceInfoEvent deviceSettings;
    s_pNvsStorageDriver->readDeviceConfig(&deviceSettings);

    esp_sleep_enable_timer_wakeup(deviceSettings.getInterval() * 1000000);
    esp_deep_sleep_enable_gpio_wakeup(BIT(USR_BTN), ESP_GPIO_WAKEUP_GPIO_LOW);

    ESP_LOGI("Control", "sleep starting");
    esp_deep_sleep_start();
}

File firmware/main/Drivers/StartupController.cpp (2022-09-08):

#include "StartupController.h"

#include "Drivers/ApplicationHardwareConfig.h"
#include "Control/ControlTask.h"
#include "Control/PushBtn/GpioIrqHandler.h"
#include "CloudLink/ConfigurationService/ConfigurationService.h"

NvsStorageDriver StartupController::s_nvsDriver;

void StartupController::initialize() {
    s_nvsDriver.initialize();

    ControlTask::setStorageDriver(&StartupController::s_nvsDriver);
    ConfigurationService::setStorageDriver(&StartupController::s_nvsDriver);
}

void StartupController::initializeGpio() {
    // Air Indicator GPIO
    gpio_reset_pin(LED_AIR_POOR);
    gpio_reset_pin(LED_AIR_MOD);
    gpio_reset_pin(LED_AIR_GOOD);

    gpio_set_direction(LED_AIR_POOR, GPIO_MODE_OUTPUT);
    gpio_set_direction(LED_AIR_MOD, GPIO_MODE_OUTPUT);
    gpio_set_direction(LED_AIR_GOOD, GPIO_MODE_OUTPUT);

    // Wlan Indicator GPIO
    // nothing to do

    // BME680 SPI GPIO
    // nothing to do

    // Usr Button GPIO  
    gpio_set_direction(USR_BTN, GPIO_MODE_INPUT);
    gpio_set_direction(PRG_SW_RST_BTN, GPIO_MODE_INPUT);

    // VBat Monitor ADC GPIO
    // TODO

    // PSU State GPIO
    // TODO
}

void StartupController::initializeSpi1() {
    // Datasheet [0] https://www.bosch-sensortec.com/media/boschsensortec/downloads/datasheets/bst-bme680-ds001.pdf
    // https://docs.espressif.com/projects/esp-idf/en/latest/esp32c3/api-reference/peripherals/spi_slave.html
    spi_bus_config_t spiBusCfg = spi_bus_config_t();
    spiBusCfg.mosi_io_num     = static_cast<int32_t>(BME680_SPI_MOSI);
    spiBusCfg.miso_io_num     = static_cast<int32_t>(BME680_SPI_MISO);
    spiBusCfg.sclk_io_num     = static_cast<int32_t>(BME680_SPI_SCK);
    spiBusCfg.data2_io_num    = -1;
    spiBusCfg.data3_io_num    = -1;
    spiBusCfg.data4_io_num    = -1;
    spiBusCfg.data5_io_num    = -1;
    spiBusCfg.data6_io_num    = -1;
    spiBusCfg.data7_io_num    = -1;
    
    spi_device_interface_config_t spiDevCfg = spi_device_interface_config_t();
    spiDevCfg.command_bits    = 0;
    spiDevCfg.address_bits    = 0;
    spiDevCfg.mode            = 0;                                       // Datasheet [0] page 40
    spiDevCfg.clock_speed_hz  = SPI_MASTER_FREQ_10M;                     // Datasheet [0] page 3
    spiDevCfg.spics_io_num    = static_cast<int32_t>(BME680_SPI_SS);
    spiDevCfg.queue_size      = 5;

    spi_bus_initialize(BME680_SPI_BUS, &spiBusCfg, SPI_DMA_DISABLED);
    spi_bus_add_device(BME680_SPI_BUS, &spiDevCfg, &s_pSpi);
}

void StartupController::initializeAdc1() {
    // TODO
}

void StartupController::initializeIrq() {
    gpio_config_t gpioConfig = gpio_config_t();
    gpioConfig.intr_type = GPIO_INTR_ANYEDGE;
    gpioConfig.pin_bit_mask = (1ULL << USR_BTN)
                            | (1ULL << PRG_SW_RST_BTN);
    gpioConfig.mode = GPIO_MODE_INPUT;
    gpioConfig.pull_up_en = GPIO_PULLUP_ENABLE;
    gpio_config(&gpioConfig);

    // install gpio service
    gpio_install_isr_service(0);
    gpio_isr_handler_add(USR_BTN, &GpioIrqHandler::onGpioIsr, (void*)USR_BTN);
    gpio_isr_handler_add(PRG_SW_RST_BTN, &GpioIrqHandler::onGpioIsr, (void*)PRG_SW_RST_BTN);
}

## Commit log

2022-07-23 Initial release for Rev.1
    [Bill of Materials-HumiMainboard.csv, Button.3MF, CaseBottoml.3MF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]
2022-07-23 Initialize LED Gpio hardware
2022-07-23 Implemented air indicator driver
2022-07-23 Added Rev1 issues for PCB
2022-07-26 Start LED blinken when a device is connected
2022-07-26 Implemented software timer for event-based approach
2022-07-26 Refactoring timer handling
2022-07-27 Fixed Timer bug
2022-07-27 Implemented SK6805 Neopixel driver with RTM hardware accelarator
2022-07-27 Update GuiUpdater task with new Neopixel driver
2022-08-07 Fixed SK6805 bug, where no LED is flashing when period is updated
    [SK6805Driver.cpp]
2022-08-08 Renamed LocalCtrlHandler to ConfigurationService
    [ConfigurationProperty.h, ConfigurationProviderIfc.h, ConfigurationService.h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]
2022-08-09 Refactored and added MQTT Service
    [ConfigurationProviderIfc.h]
2022-08-16 Just ensure device does not fail when broker is not configured
2022-08-16 Added nvs partition layout
    [partitions.csv]
2022-08-16 Start service mode when wifi connection failed
    [ControlTask.cpp]
2022-08-17 Renamed ConfigurationProviderIfc to KeyValueStorageIfc
    [ConfigurationService.h]
2022-08-18 Added Room to DeviceSettings
2022-08-19 Improved persistency stability
    - Fixed bug where string content is loaded from flash
    - refactored KeyValueStorageIfc for better maintainability
    [ConfigurationService.h]
2022-08-19 Added interval to DeviceSettingsEvent
2022-09-05 Added BME680 driver
2022-09-07 Add gas resistance
2022-09-08 Show sensor status on ui
2022-09-08 Fixed full queue error
    [ControlTask.cpp]
2022-09-08 Fixed out of timers exception
2022-09-08 Increase available timers
2022-09-08 implemented Button SM for different actions
2022-09-08 Replaced button timer with RTOS duration
2022-09-08 Reset flash storage on long RST press
    [ControlTask.cpp]
2022-09-08 Disable/Enable UI based on USR button
2022-09-08 Fixed GPIO edge irq
    [GpioIrqHandler.cpp]
2022-09-08 reset device on short rst press
    [ControlTask.cpp]
2022-09-08 Remove room configuration, it is not used in device
2022-09-08 Added BatteryStatusEvent
2022-09-08 Implement device info event (WIP)
2022-09-08 Send device info to mqtt broker
    [ControlTask.cpp]
2022-09-08 Basic Structure for Power Management Task
2022-09-09 Fixed multiple sensor acqure in wrong time interval
    [ControlTask.cpp]
2022-09-09 Show wifi signal strength with led indicator
2022-09-09 Renamed DeviceInfoEvent to DeviceStatusEvent
2022-09-09 Renamed DeviceSettingsEvent to DeviceInfoEvent
2022-09-09 Added DeviceConfigEvent
2022-09-09 Fixed IDF bug when switch esp netif from STA to AP
2022-09-09 increase power mgnt refresh rate
